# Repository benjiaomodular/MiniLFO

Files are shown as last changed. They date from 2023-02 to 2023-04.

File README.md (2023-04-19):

# MiniLFO

A super simple 2HP triangle wave LFO for Eurorack modular synth. This is roughly based on [David Haillant's Simple LFO](https://www.davidhaillant.com/wp/wp-content/uploads/lfo-1.5b-20210205.pdf).

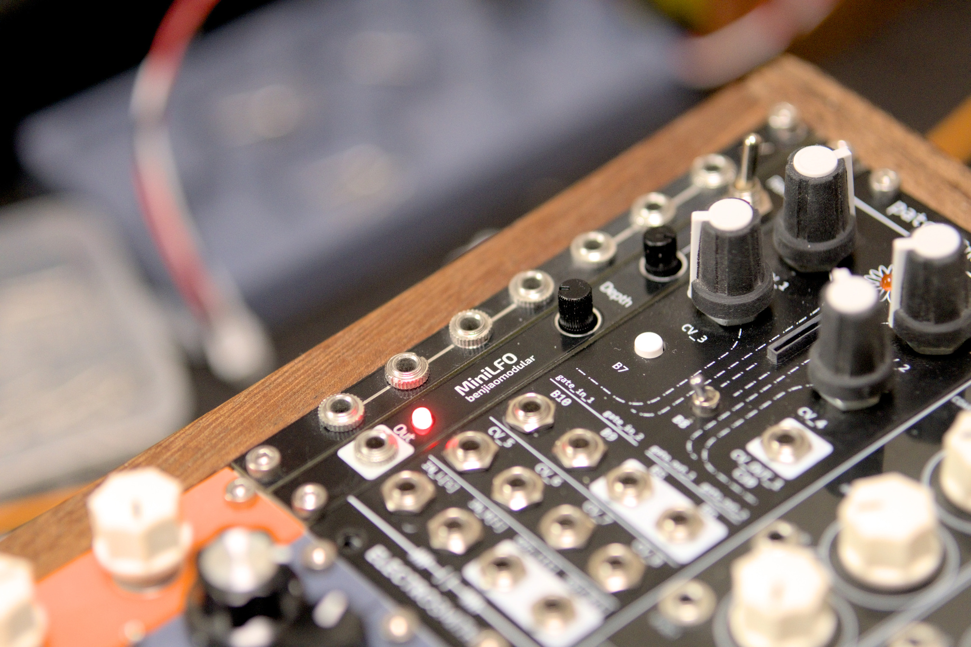
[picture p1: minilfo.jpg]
MiniLFO


More info on my website: https://benjiaomodular.com/posts/minilfo

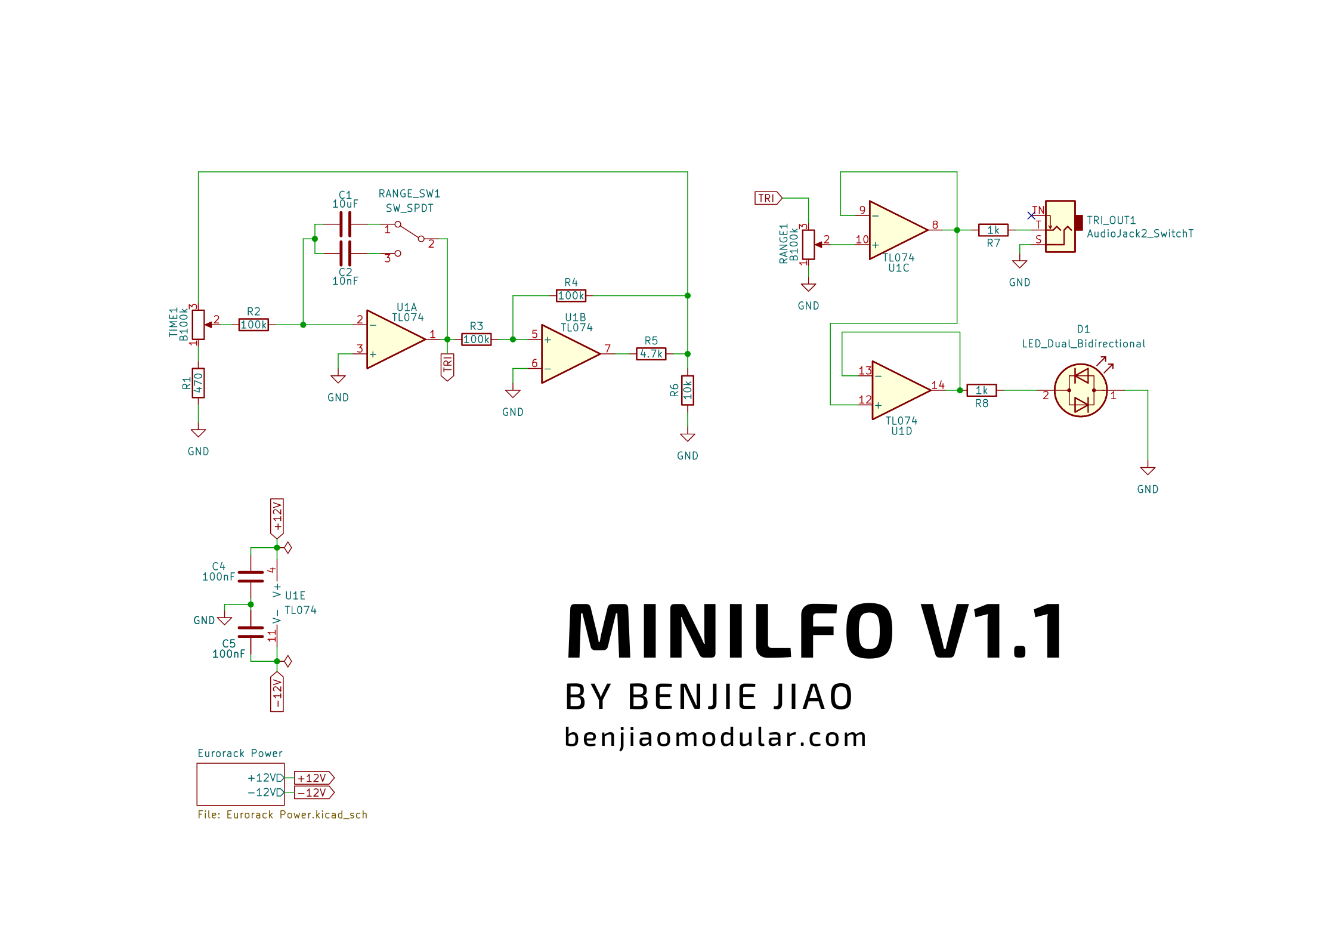
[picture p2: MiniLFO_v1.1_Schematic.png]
MiniLFO Schematic


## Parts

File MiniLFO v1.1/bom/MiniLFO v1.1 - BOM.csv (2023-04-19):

null | Sourced | Placed | References | Value | Footprint | Manufacturers Name | Manufacturers Part Number | Quantity
1 | ✓ | ✓ | C3, C6 | 22uF | C_0805_2012Metric_Pad1.18x1.45mm_HandSolder | YAGEO | CC0805KRX7R9BB104 | 2
2 | ✓ | ✓ | C4, C5 | 100nF | C_0603_1608Metric_Pad1.08x0.95mm_HandSolder | KEMET | R82EC3100DQ70K | 2
3 |  |  | C1 | 10uF | Capacitor_Radial_D5.0mm_P2.5mm | Panasonic | ECE-A1VN100UB | 1
4 |  |  | C2 | 10nF | Capacitor_Rect_L7.2mm_W2.5mm_P5.00mm | KEMET | MMK5103K50J01L4BULK | 1
5 | ✓ | ✓ | R2, R3, R4 | 100k | R_0603_1608Metric_Pad0.98x0.95mm_HandSolder | YAGEO | RC0603FR-07100KL | 3
6 | ✓ | ✓ | R7, R8 | 1k | R_0603_1608Metric_Pad0.98x0.95mm_HandSolder | YAGEO | RC0603FR-071KL | 2
7 | ✓ | ✓ | R1 | 470 | R_0603_1608Metric_Pad0.98x0.95mm_HandSolder | YAGEO | RC0603FR-7W470RL | 1
8 | ✓ | ✓ | R5 | 4.7k | R_0603_1608Metric_Pad0.98x0.95mm_HandSolder | YAGEO | RC0603FR-074K7L | 1
9 | ✓ | ✓ | R6 | 10k | R_0603_1608Metric_Pad0.98x0.95mm_HandSolder | YAGEO | AC0603FR-0710KL | 1
10 |  |  | D1 | LED_Dual_Bidirectional | LED_D3.0mm | KENTO | 3ARG4HWC | 1
11 | ✓ | ✓ | U1 | TL074 | SOIC-14_3.9x8.7mm_P1.27mm | STMicroelectronics | TL074ACDT | 1
12 |  |  | RANGE1, TIME1 | B100k | Potentiometer_RV09 | Alpha (Taiwan) | RV09AF-40-20K-B100K | 2
13 |  |  | RANGE_SW1 | MTS-102 SPDT | ToggleSwitch_MTS-102_SPDT | Tayda Electronics | Mini Toggle Switch SPDT On-On | 1
14 |  |  | TRI_OUT1 | PJ-3001F | AudioJack_3.5mm | Tayda Electronics | PJ-3001F | 1
15 |  |  | J1 | IDC_2x05 | IDC-Header_2x05_P2.54mm_Vertical | XKB Connectivity | X9555WV-2X05-6TV01 | 1

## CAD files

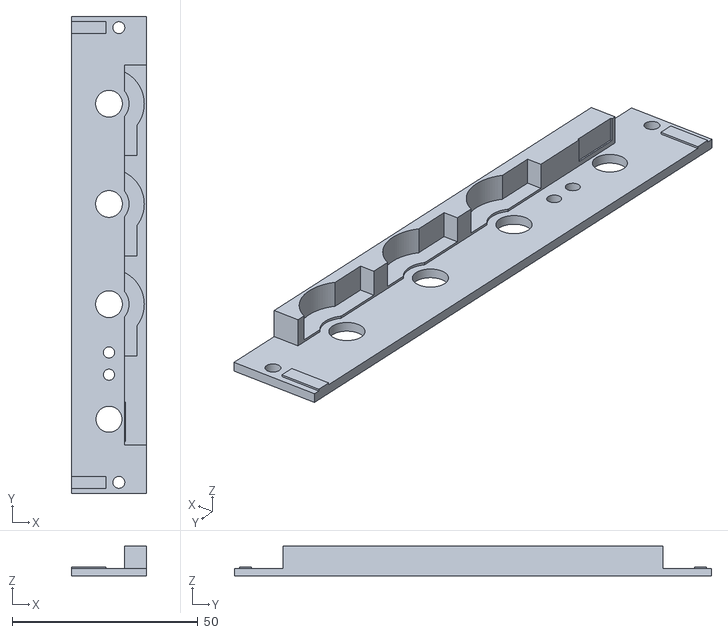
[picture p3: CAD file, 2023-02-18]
OpenSCAD/MiniLFO - Panel (3D Printed).stl
20.3 x 128.5 x 8.00

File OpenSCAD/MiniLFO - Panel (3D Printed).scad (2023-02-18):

use <components/jack_35mm.scad>
use <components/led_3mm.scad>
use <components/pot_alpha_16mm.scad>

$fn=100; 
hp = 4;

EURORACK_H = 128.5;
EURORACK_W = 5.08;
THICKNESS = 2; // thickness

w = hp * EURORACK_W;


module main(){
    cube([w, EURORACK_H, THICKNESS]);
    translate([11, 1.4,-0.4]) cube([w-11, 3.2, 0.4]);
    translate([11, EURORACK_H-4.6,-0.4]) cube([w-11, 3.2, 0.4]);
    
    // rib
    rib_height = 6;
    rib_margin = 13;
    rib_thickness = 6;

    translate([0, rib_margin,-rib_height]) cube([rib_thickness, EURORACK_H-rib_margin*2, rib_height]);
    // --
}


module logo(x, y){
    // label
    translate([x, y, THICKNESS-0.6]) {
        rotate([0, 0, 90]) {
            linear_extrude(height=0.6) {
                text("benjiaomodular",
                     font="Liberation Sans",
                     size=6);
            }
        }
    }
}

module blank_panel(){
    difference() {
        main();
        
        union(){
            // mounting holes
            translate([7.5, 3, 0]) cylinder(r=1.6, h=10, center=true);
            translate([7.5, EURORACK_H-3, 0]) cylinder(r=1.6, h=10, center=true);
            
            translate([2, 118, 1]) {
                linear_extrude(height=1.4) {
                    text("MiniLFO",
                         font="Liberation Sans",
                         size=3);
                }
            }
            
            translate([EURORACK_W * 2, 105, 0])  pot_alpha_16mm();
            translate([EURORACK_W * 2 - 6, 105-14.5, 1]) {
                linear_extrude(height=1.4) {
                    text("RATE",
                         font="Liberation Sans",
                         size=3);
                }
            }
            
            translate([EURORACK_W * 2, 78, 0])   pot_alpha_16mm(); 
            translate([EURORACK_W * 2 - 8, 78-14.5, 1]) {
                linear_extrude(height=1.4) {
                    text("RANGE",
                         font="Liberation Sans",
                         size=3);
                }
            }
            
            translate([EURORACK_W * 2, 51, 0])   pot_alpha_16mm(); 
            
            translate([EURORACK_W * 2, 38]) led_3mm();
            translate([EURORACK_W * 2, 32]) led_3mm();
            
            translate([EURORACK_W * 2, 20, 0]) jack_35mm();
            
            
        }
    }
}

translate([w, 0, 2]) rotate([0, 180, 0]) blank_panel();
//translate([w, 0, 2]) color([1,0,0]) rotate([0, 180, 0]) logo(13, 16);

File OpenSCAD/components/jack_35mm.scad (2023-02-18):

$fn=100; 

module jack_35mm(x, y, r){
    
    
    translate([0, 0, 2.5]){
        cylinder(r=3.5, h=5, center=true);
        
    }
    
    translate([0, 0, -0.5]) {
    
        cylinder(r=3.75, h=1, center=true);
        
        translate([-1.5, 0, -13.5]){
            cube([3, 10, 13]);
        }
    }
    
    
    translate([-4.5, -6, -14]){
        cube([9, 10.6, 13]);
    }
    

}

jack_35mm(0, 0, 0);

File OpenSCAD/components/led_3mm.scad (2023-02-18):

$fn=100; 

module led_3mm(){
    cylinder(r=1.5, h=5, center = true);
    translate([0, 0, -2]) cylinder(r=2, h=4, center = true);
}

led_3mm();

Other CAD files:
OpenSCAD/components/pot_alpha_16mm.scad
OpenSCAD/components/mounting_tab.scad

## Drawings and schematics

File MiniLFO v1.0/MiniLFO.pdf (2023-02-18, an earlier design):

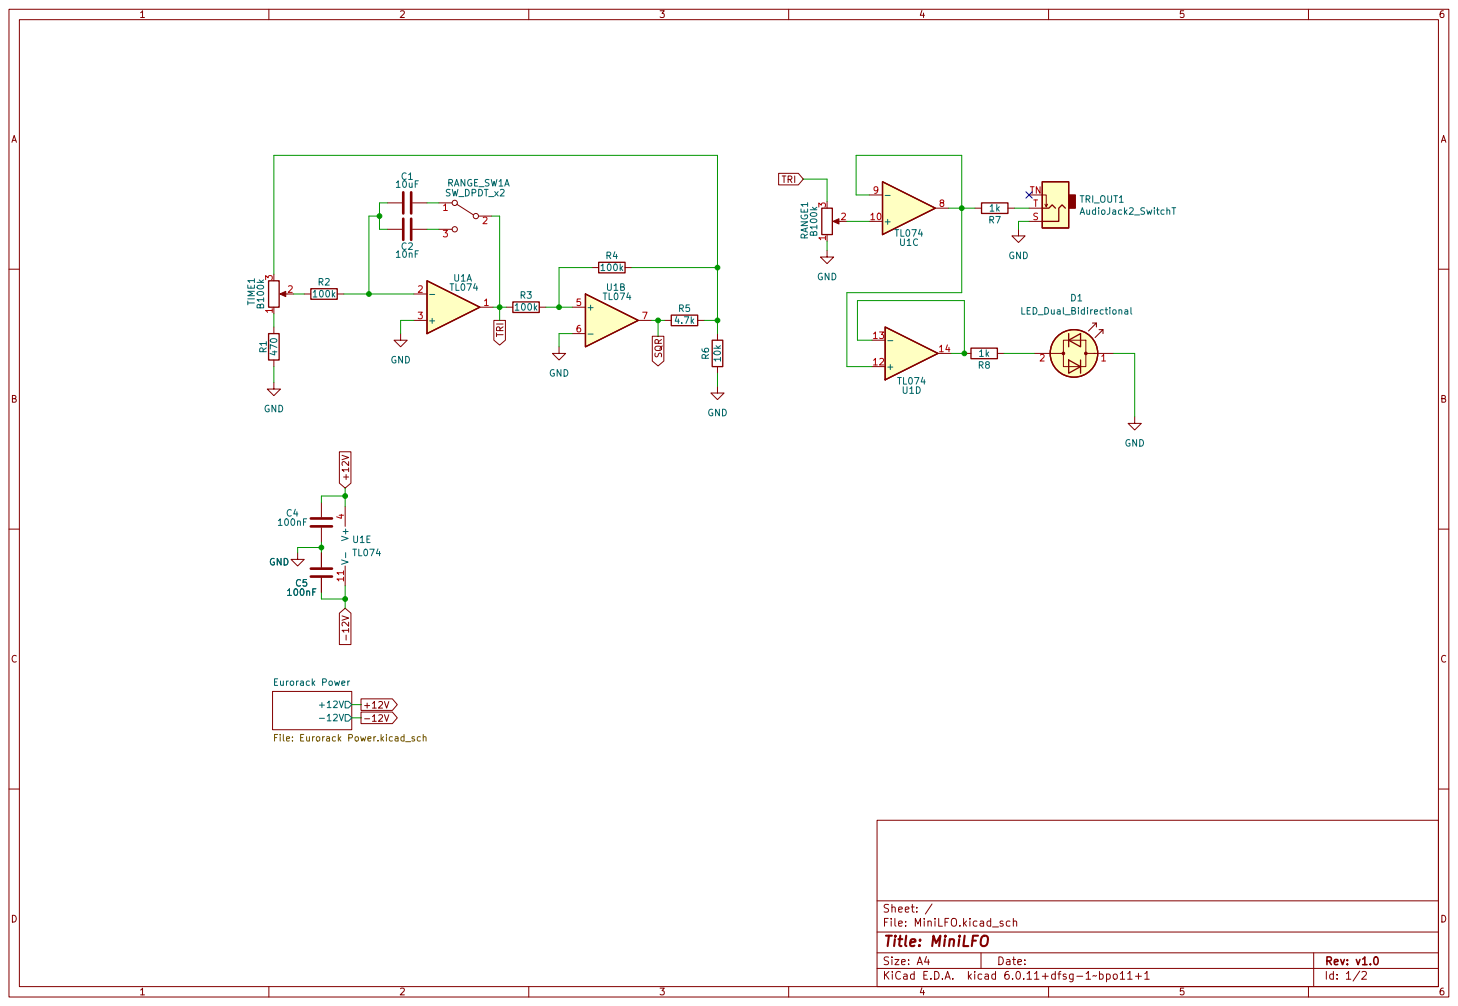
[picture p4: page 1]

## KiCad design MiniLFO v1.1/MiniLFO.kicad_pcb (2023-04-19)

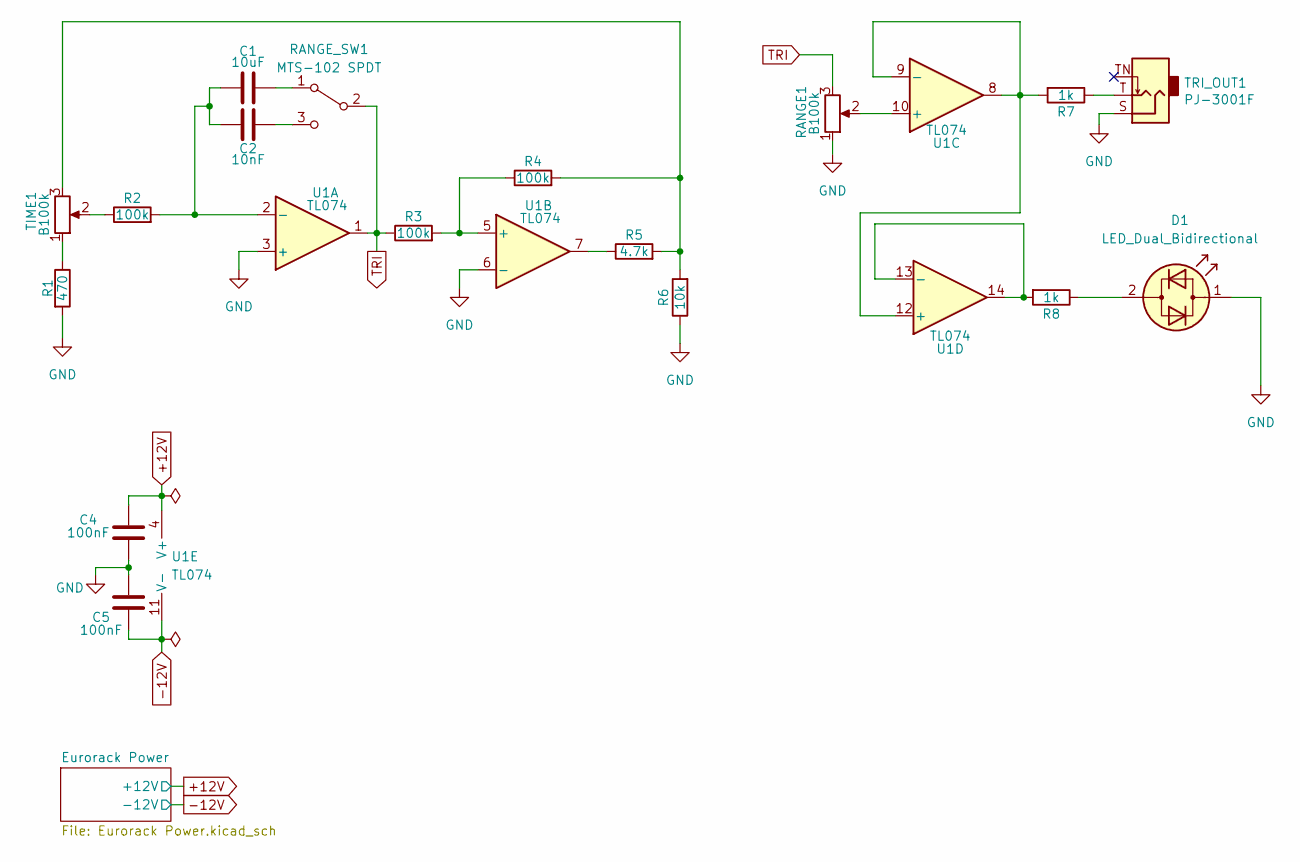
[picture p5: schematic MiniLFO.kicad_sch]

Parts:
C1: 10uF; Capacitor_Radial_D5.0mm_P2.5mm; Manufacturers Part Numb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 ECE-A1VN100UB
C2: 10nF; Capacitor_Rect_L7.2mm_W2.5mm_P5.00mm; Manufacturers Part Numb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 MMK5103K50J01L4BULK
C4, C5: 100nF; C_0603_1608Metric_Pad1.08x0.95mm_HandSolder; Manufacturers Part Numb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 R82EC3100DQ70K
D1: LED_Dual_Bidirectional; LED_D3.0mm; Manufacturers Part Numb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 3ARG4HWC
R1: 470; R_0603_1608Metric_Pad0.98x0.95mm_HandSolder; Manufacturers Part Numb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 RC0603FR-7W470RL
R2, R3, R4: 100k; R_0603_1608Metric_Pad0.98x0.95mm_HandSolder; Manufacturers Part Numb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 RC0603FR-07100KL
R5: 4.7k; R_0603_1608Metric_Pad0.98x0.95mm_HandSolder; Manufacturers Part Numb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 RC0603FR-074K7L
R6: 10k; R_0603_1608Metric_Pad0.98x0.95mm_HandSolder; Manufacturers Part Numb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 AC0603FR-0710KL
R7, R8: 1k; R_0603_1608Metric_Pad0.98x0.95mm_HandSolder; Manufacturers Part Numb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 RC0603FR-071KL
RANGE1: B100k; Potentiometer_RV09; Manufacturers Part Numb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 RV09AF-40-20K-B100K
RANGE_SW1: MTS-102 SPDT; ToggleSwitch_MTS-102_SPDT; Manufacturers Part Numb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 Mini Toggle Switch SPDT On-On
TIME1: B100k; Potentiometer_RV09; Manufacturers Part Numb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 RV09AF-40-20K-B100K
TRI_OUT1: PJ-3001F; AudioJack_3.5mm; Manufacturers Part Numb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 PJ-3001F
U1: TL074; SOIC-14_3.9x8.7mm_P1.27mm; Manufacturers Part Numb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 TL074ACDT

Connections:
+12V: C4.2, U1.4 (V+); also elsewhere on the board
-12V: C5.1, U1.11 (V-); also elsewhere on the board
GND: C4.1, C5.2, D1.1 (KA), R1.2, R6.1, RANGE1.1, TRI_OUT1.S, U1.3 (+), U1.6 (-); also elsewhere on the board
unnamed: C1.1, C2.1, R2.2, U1.2 (-)
unnamed: C1.2, RANGE_SW1.1 (A)
unnamed: C2.2, RANGE_SW1.3 (C)
unnamed: D1.2 (AK), R8.1
unnamed: R1.1, TIME1.1
unnamed: R2.1, TIME1.2
unnamed: R3.2, R4.1, U1.5 (+)
unnamed: R4.2, R5.2, R6.2, TIME1.3
unnamed: R5.1, U1.7
unnamed: R7.1, TRI_OUT1.T
unnamed: R7.2, U1.8, U1.9 (-), U1.12 (+)
unnamed: R8.2, U1.13 (-), U1.14
unnamed: RANGE1.2, U1.10 (+)
TRI: R3.1, RANGE1.3, RANGE_SW1.2 (B), U1.1

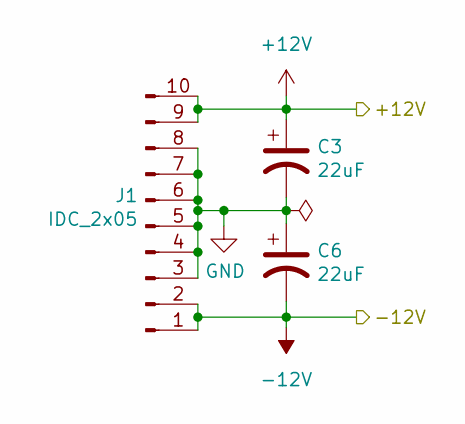
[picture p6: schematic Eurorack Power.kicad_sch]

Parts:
C3, C6: 22uF; C_0805_2012Metric_Pad1.18x1.45mm_HandSolder; Mfg # CC0805KRX7R9BB104; LCSC Part # C49678
J1: IDC_2x05; IDC-Header_2x05_P2.54mm_Vertical; Manufacturers Part Numb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 X9555WV-2X05-6TV01; LCSC Part # C706914

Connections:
+12V: C3.1, J1.9, J1.10; also elsewhere on the board
-12V: C6.2, J1.1, J1.2; also elsewhere on the board
GND: C3.2, C6.1, J1.3, J1.4, J1.5, J1.6, J1.7, J1.8; also elsewhere on the board

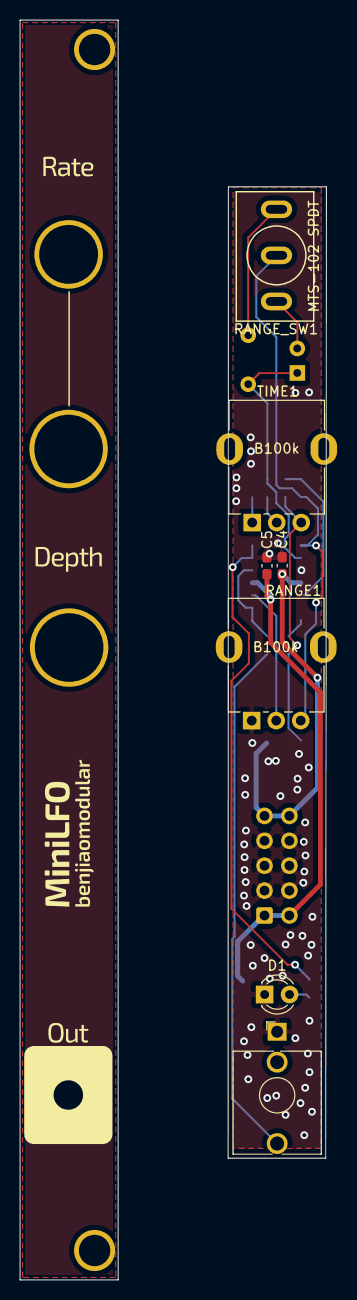
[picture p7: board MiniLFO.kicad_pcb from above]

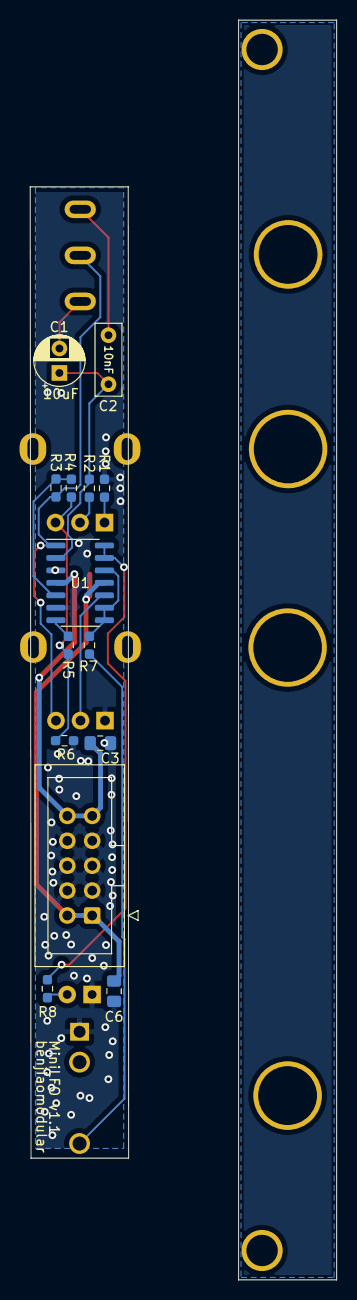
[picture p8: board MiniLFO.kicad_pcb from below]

Board: 2 copper layers, 10.0 x 99.1 mm, 21 parts (14 on the bottom side), 17 nets.

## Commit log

2023-02-18 hello git
    [Eurorack Power.kicad_sch, MiniLFO - Panel (3D Printed).scad, MiniLFO - Panel (3D Printed).stl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]
2023-04-19 Updated docs
    [Eurorack Power.kicad_sch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]
2023-04-19 Show schematic
2023-04-19 Added complete bom
    [MiniLFO - BOM.csv, MiniLFO.kicad_sch]
2023-04-19 Renamed BOM
    [MiniLFO v1.1 - BOM.csv]
2023-04-19 Updated BOM with parts numbers
    [MiniLFO v1.1 - BOM.csv, MiniLFO.kicad_pcb]
